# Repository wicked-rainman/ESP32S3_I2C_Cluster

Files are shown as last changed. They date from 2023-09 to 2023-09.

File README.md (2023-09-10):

## ESP32-S3 I2C Cluster

An ESP32S3 I2C cluster that captures WiFi beacon packets and outputs records that allow for a network map to be drawn (I've been using the .dot processor and Gephi for the followon processing).

### Background

Outside of my office window, I tend to see around 60 WiFi networks (Some hidden, some not). It's not much of a performance guide, but tests show that this cluster and the I2C bus easily keeps up with the beacon generation rate. 

Any drawn network diagrams tend to get bogged down with probes from rolling macs generated by mobile phones. I tend to just filter these out with post processing (often by Vendor OUI), but even after doing that, the inter-relationship between various WiFi networks was surprising to me.

Many of the domestic APs observed seem to offer multiple WiFi networks for roving users. These devices tend to use a rolling Mac address that is similar to the advertised network's Mac (For example, "Bt-WiFi" seems to offer a home network, a public network and one that is hidden). Where this is the case, the SSID for the roving network is associated with the fixed Mac that relates to the visible home user SSID (This is a function of the Network scanning node).

As I'm only really interested in trying to draw network maps, the Master node performs a dedupe based on the concatenation of the first three Mac addresses in any beacon packets. The dedupe "buffer" is in fact two fifo buffers. One for real macs and the other for rollers. The rolling mac buffer is roughly four times bigger, because that seems to suit the local traffic I see.

I've had a go at doing this because people tend to pour scorn on folk making mini clusters, often saying it's a waste of time. I think it's all about the use case. Using M5StampS3 modules, this cluster cost about half the price of a Raspberry Pi and it seems quite effective. Logic flow for this cluster is as follows:

### I2C Startup
Master I2C node makes connection attempts to the three other nodes. If an Ack is not received processing stops and the Master node LED flashes red. If there is a USB Serial connection made, diagnostic messages indicate which node cannot be contacted.

```mermaid
sequenceDiagram
    autonumber
    Master->>Oui node: I2C Poll 0x57
    activate Master
    Oui node-->>Master: Poll Ack
    Master->>WiFi node: I2C Poll 0x56
    WiFi node-->>Master: Poll Ack
    Master->>Beacon node: I2C Poll 0x55
    Beacon node-->>Master: Poll Ack
    deactivate Master

```

If all nodes appear to be live, the master node processing then waits for a button press before activation. During this "dormant" period, two of the nodes start processing:
* <b>WiFi node</b>: 
Starts to scan for WiFi networks. The details of each new network are stored in a structure, indexed by BSSID, with a string value for the SSID. The structures are held in an array that holds up to 200 records. If this count is exceeded no further records are added. An I2C ISR access this buffer to answer SSID lookups requested by the master, so there isn't the processing time available to make the array a link list.

* <b>Beacon node</b>:
Starts to cycle through WiFi channels, storing any management beacon packets it can see. An I2C ISR sits waiting for the master to request the next beacon. Up to 255 beacons are stored in a FIFO buffer and the last but one beacon packet is returned. 

* <b>Oui node</b>
The Oui node has a pre-loaded array of Vendor strings indexed by the four byte OUI value extracted from a Mac. This array can be updated with fresh values by using Netcat on port 180. The node always listens to this port for a connection and updates can take place at any stage. 

### Running

```mermaid
sequenceDiagram
    autonumber
    Master->>Beacon node: Request next beacon
    Beacon node-->>Master: Beacon header
    Master->>Oui node: Request Mac Addr vendor
    Oui node-->> Master: Vendor or Unk
    Master->>WiFi node: Request SSID
    WiFi node-->>Master: SSID or Unk
```
1.  The master requests the next beacon packet.
2.  The beacon node returns the last available packet
3. If the ADDR1 field in the packet is not a broadcast MAC, the master extracts the four most significant bytes of the Mac address and sends it to the Oui node.
4.  The Oui node looks these four bytes up in it's OUI table and if found, returns the Vendor details or the string OUI_Unk.
5. The Master then sends the ADDR1 mac address to the WiFi node.
6. The WiFi node looks the Mac address up to see if it's seen an association with an SSID. If found, an SSID string is returned or the value NET_Unk. Macs can be short (Middle four bytes) or long (All 6 bytes). This helps with the resolution of public access points where a rolling mac address is associated with a publically available SSID (Such as Virgin_Media, BT-WiFi Etc). In this instance, the real home SSID is returned.

This process is repeated for ADDR2 and (if it's different from ADDR2) ADDR3.

### Data output format

The master node generates a single CSV type record for each unique beacon packet it sees (In this instance, unique means the concatenation of the first three Mac addresses extracted from the beacon packet have not been seen before). The output format is as follows:
+ <b>Addr</b>1 (Six 2-digit hex numbers)

+ <b>Addr2</b> (Six 2-digit hex numbers)

+ <b>Addr3</b> (Six 2-digit hex numbers) 

+ <b>Addr1 vendor</b> (Vendor string or "Roll" for rolling mac, "Bcast" for a broadcast)

+ <b>Addr1 SSID</b> (SSID string or "NET_Unk")

+ <b>Addr1 OUI</b> (Vendor string or "OUI_Unk")

+ <b>Addr2 vendor</b> (Vendor string or "Roll" for rolling mac, "Bcast" for a broadcast)

+ <b>Addr2 SSID</b> (SSID string or "NET_Unk")

+ <b>Addr2 OUI</b> (Vendor string or "OUI_Unk")

+ <b>Addr3 vendor</b> (Empty if ADDR2=ADDR3, else Vendor string or "Roll" for rolling mac, "Bcast" for a broadcast)

+ <b>Addr3 SSID</b> (Empty if ADDR2=ADDR3, else SSID string or "NET_Unk")

+ <b>Addr3 OUI</b> (Empty if ADDR2=ADDR3 else endor string or "OUI_Unk")

* <b>ADDR2 Channel number</b> (Integer)

+ <b>Beacon seq #</b> (Integer. Rolling buffer position)

<table>
  <tr>
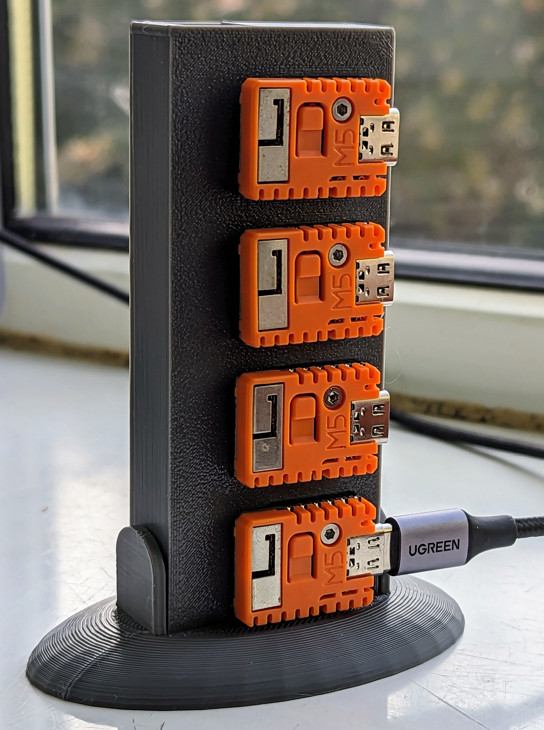
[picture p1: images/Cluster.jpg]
    <td></td>
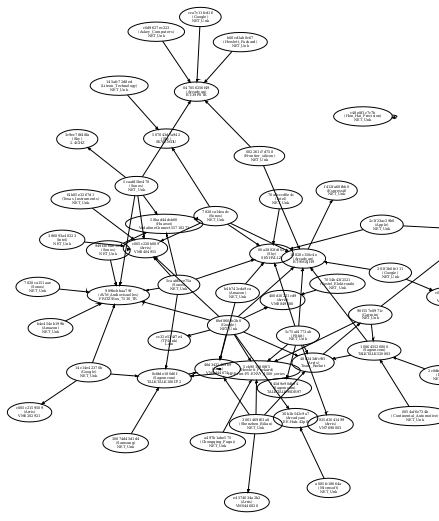
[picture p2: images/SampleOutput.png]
    <td></td>
   </tr> 
</table>

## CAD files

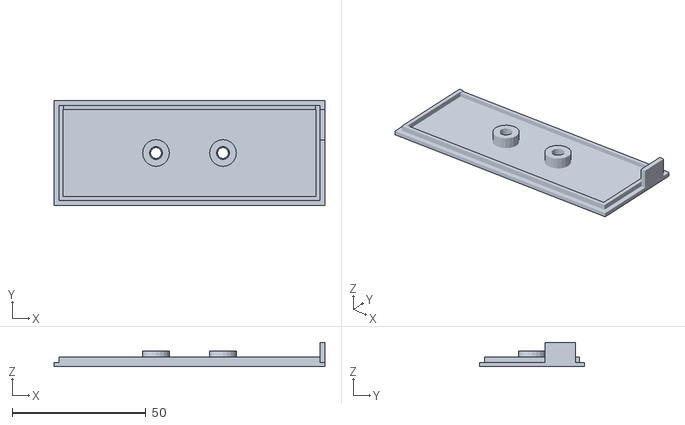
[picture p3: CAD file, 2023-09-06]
STL/Back.stl
101.2 x 39.3 x 9.00

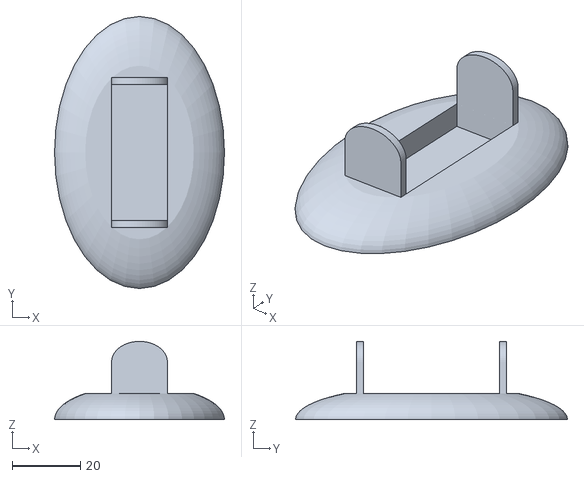
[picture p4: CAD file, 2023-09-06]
STL/Stand.stl
50.0 x 80.0 x 23.0

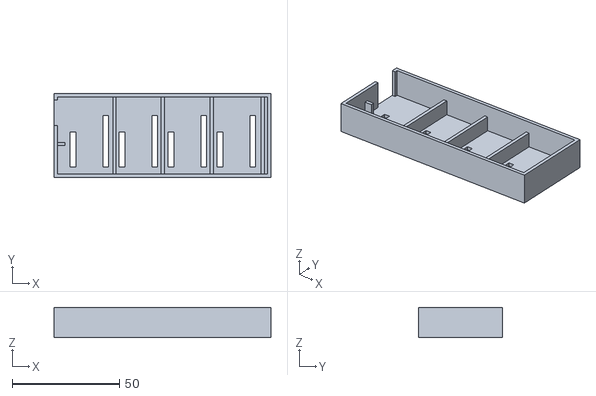
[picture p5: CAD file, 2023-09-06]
STL/Case.stl
101.2 x 39.3 x 14.0

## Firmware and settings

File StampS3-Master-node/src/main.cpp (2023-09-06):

#include "main.h"

void setup() {
  bool error=false;
  bool toggle=true;
  pinMode(PIN_BUTTON, INPUT);
  FastLED.addLeds<WS2812,LED, GRB>(leds, NUM_LEDS);
  USBSerial.begin(115200);
  vTaskDelay(1200); //This is how long Espressif seem to think the USB serial port takes to init.

  //
  // This is the I2C Master.                                                      
  // ------------------------                                                     
  // It's function is as follows:                                                 
  //                                                                              
  // 1. Make sure that the three cluster node slaves can be found                 
  //    on the I2C bus.                                                           
  //                                                                              
  // 2.Request the latest beacon packet via I2c from the Beacon node.             
  //  There is no guarantee that every beacon packet will be processed, but
  //  they are extracted from a circular buffer on the beacon node end and in 
  //  practice, very little(if any) seem to get lost.
  //
  // 3.Extract the three Mac addresses from the beacon packet
  //  and see if all three combined (18 bytes) have been seen before.
  //  We are only intrested in TA, so if it's a duplicate just ignore it.
  //
  // 4.For each of the first three Mac addresses in the beacon, check to
  // see if the address is rolling. If it is, mark it as such.
  // If it's not a rolling mac, ask the OUI node to look up the vendor,
  // then ask the network scanning node if there is an associated SSID.
  //
  // 5. Output all that gleamed information via the serial port and
  // as a broadcast on UDP port 5128.
  //
  USBSerial.printf("This is the master node\n");
  Wire.setPins(13,15);
  Wire.begin();
  vTaskDelay(5000);
  Wire.beginTransmission(0x55);
  if(!Wire.endTransmission()) USBSerial.printf("Found I2c device: 0x55\n");
  else error=true;
  Wire.beginTransmission(0x56);
  if(!Wire.endTransmission()) USBSerial.printf("Found I2c device: 0x56\n");
  else error=true;
  Wire.beginTransmission(0x57);
  if(!Wire.endTransmission()) USBSerial.printf("Found I2c device: 0x57\n");
  else error=true;
  if(error) {
    //----------------------------------------------------------------------//
    // Could not contact the three nodes, so loop forever flashing the led  //
    //----------------------------------------------------------------------//
    while(true) {
      toggle = !toggle;
      if(toggle) leds[0] = 0xff0000;
      else leds[0] = 0x000000;   
      FastLED.show();
      vTaskDelay(200);
    }
  }
  //
  // Required nodes were found.   
  // Start up WiFi connection, waiting forever if it's not there    
  //
  WiFi.begin(ssid,password);
  while(WiFi.status() != WL_CONNECTED) {
      leds[0] = 0x0000ff;
      FastLED.show();
      vTaskDelay(200);
      leds[0] = 0x000000;
      FastLED.show();
      vTaskDelay(200);
  }
  //
  // Open up the UDP broadcast port    
  //
  beaconPort.begin(UDPBEACON_PORT);

//
// Wait for a button press before running. This gives a chance for a new OUI table   
// to be NC'd up to the OUI node and allows for the Network scanner to learn for      
// a while. The longer the time delay before pressing the button the better. This    
// is because the scanner performs on-the-fly editing of SSIDs to resolve            
// rolling AP mac addresses. In practice, one or two mins before activation          
// seems a good time to chill.                                                       
//
  leds[0] = 0x0f0000;
  FastLED.show();
  while(1) {
    if(!digitalRead(PIN_BUTTON)) {
      vTaskDelay(20);
      if(!digitalRead(PIN_BUTTON)) {
        leds[0] = 0x000000;
        FastLED.show();
        vTaskDelay(2000);
        break;
      }
    }
  }
  //
  // Initialise the two ring buffers used by the concentrator function (Dedupes records based   
  // on full or rolling mac addresses). For rolling macs, only the central 4 bytes are stored   
  // (They get put in the short buffer). Full macs get stuffed into the long buffer.            
  // If either get's found, then the beacon records are dropped as "seen before"                
  //
  memset(DedupeBufLong,0,DEDUPE_LONG_BUF_SIZE);
  memset(DedupeBufShort,0,DEDUPE_SHORT_BUF_SIZE);
}
//-----------------------------------------------------------------------------

void loop() {
  static uint8_t Addr1[6];
  static uint8_t Addr2[6];
  static uint8_t Addr3[6];
  static char Addr1Oui[40];
  static char Addr2Oui[40];
  static char Addr3Oui[40];
  static char SsidStr1[200];
  static char SsidStr2[200];
  static char SsidStr3[200];
  static uint8_t ChannelNo;
  static uint8_t SequenceNo;
  static uint8_t BroadcastOui[3]={255,255,255};
  char beaconStr[BEACON_RECORD_SIZE];


  //If a new beacon packet is available
  if(FetchNextBeacon()) {
    // If we've not seen the three combined Mac addresses before
    if(Concentrate(buf)) {
      leds[0] = 0x000f00;
      FastLED.show();
      memcpy(Addr1,buf,6);
      memcpy(Addr2,buf+6,6);
      memcpy(Addr3,buf+12,6);
      ChannelNo=buf[18];
      SequenceNo=buf[19];

      //
      //  Deal with Addr1 (Often broadcast)                               
      //
      
      if (!memcmp(Addr1,BroadcastOui,3)) {  //If it's a broadcast mac
        strcpy(Addr1Oui,"Bcast");           //Don't look up the OUI
        strcpy(SsidStr1,"NET_Unk");         //Don't look up the SSID
      }
      else if(RollingMac(Addr1[0])) {       //If it's a rolling mac  
        strcpy(Addr1Oui,"Roll");            //Don't look up the OUI, set it to Roll
        ResolveSSID(Addr1,SsidStr1);      //Look for previous assoc with an SSID
      }
      else {                                //It's a normal mac
        ResolveDevice(Addr1,Addr1Oui);      //Look up the OUI
        ResolveSSID(Addr1,SsidStr1);      //Look up the SSID
      }

      //
      //  Deal with Addr2                                                
      //

      if(RollingMac(Addr2[0])) {            //If it's a rolling mac (no broadcasts in Addr2)
        strcpy(Addr2Oui,"Roll");            //Set OUI to Roll
        ResolveSSID(Addr2,SsidStr2);      //Look for an SSID match
      }
      else {                                // It's a normal mac.
        ResolveDevice(Addr2,Addr2Oui);      //Look up the OUI
        ResolveSSID(Addr2,SsidStr2);      //Look up the SSID
      }

      //
      //  Deal with Addr3 if it's not the same as Addr2                   
      //

      if(memcmp(Addr2,Addr3,6)) {             //If Addr2 is different from Addr3
        if (!memcmp(Addr3,BroadcastOui,3)) {  //If it's a broadcast mac
          strcpy(Addr3Oui,"Bcast");           //Set OUI to roll
          strcpy(SsidStr3,"NET_Unk");         //Set SSID to Unknown
        }
        else if(RollingMac(Addr1[0])) {       //If it's a rolling mac  
          strcpy(Addr3Oui,"Roll");            //Set OUI to roll
          ResolveSSID(Addr3,SsidStr3);      //Look up SSID
        }
        else {                                //It's a normal mac
          ResolveDevice(Addr3,Addr3Oui);      //Look up OUI
          ResolveSSID(Addr3,SsidStr3);      //Look up SSID
        }
      }
      else {                                  //MAC addr1 and addr2 the same
        SsidStr3[0]='\0';                     //Set SSID to null
        Addr3Oui[0]='\0';                     //Set OUI to null
      }
      
      //
      // Produce the output
      //
      snprintf(beaconStr,BEACON_RECORD_SIZE,"%02x%02x%02x%02x%02x%02x,%02x%02x%02x%02x%02x%02x,%02x%02x%02x%02x%02x%02x,%s,%s,%s,%s,%s,%s,%d,%d\n",
          Addr1[0],Addr1[1],Addr1[2],Addr1[3],Addr1[4],Addr1[5],
          Addr2[0],Addr2[1],Addr2[2],Addr2[3],Addr2[4],Addr2[5],
          Addr3[0],Addr3[1],Addr3[2],Addr3[3],Addr3[4],Addr3[5],
          Addr1Oui,SsidStr1,Addr2Oui,SsidStr2,Addr3Oui,SsidStr3,
          ChannelNo,SequenceNo);
          UdpWrite(&beaconPort,SendIP,UDPBEACON_PORT,beaconStr);
          USBSerial.printf("%s",beaconStr);

    }
    leds[0] = 0x000000;
    FastLED.show();
  }
}

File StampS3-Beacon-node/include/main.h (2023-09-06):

#include <WiFi.h>
#include <FastLED.h>
#include "esp_wifi.h"
#include "esp_wifi_types.h"
#include "esp_system.h"
#include "esp_event.h"
#include "esp_event_loop.h"
#include "nvs_flash.h"
#include "driver/gpio.h"
#include "defines.h"
#include "I2CBeaconSlave.h"
#include "WiFiPacketHandler.h"
SemaphoreHandle_t xShmem;
CRGB leds[NUM_LEDS];
uint8_t led_ih = 0;
uint8_t led_status = 0;
static void wifi_sniffer_packet_handler(void *buff, wifi_promiscuous_pkt_type_t type);
uint8_t level = 0, channel = 0;
uint8_t BeaconStore[BEACON_CACHE_SIZE][BEACON_REC_SIZE];
uint8_t RingBuffPos=0;
uint8_t channelSequence[CHANNEL_COUNT]={1,6,11,3,4,1,6,11,8,9,1,6,11,2,7,1,6,11,5,10};
uint8_t channelCount=CHANNEL_COUNT;

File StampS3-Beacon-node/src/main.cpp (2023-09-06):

#include "main.h"

//-------------------------------------------------------------------------------------------
void setup() {
  USBSerial.begin(115200);
  USBSerial.flush();
  vTaskDelay(1200);
  FastLED.addLeds<WS2812,LED, GRB>(leds, NUM_LEDS);
  xShmem = xSemaphoreCreateBinary();
  xSemaphoreGive(xShmem);
  nvs_flash_init();
  tcpip_adapter_init();
  wifi_init_config_t cfg = WIFI_INIT_CONFIG_DEFAULT();
  esp_wifi_init(&cfg);
  esp_wifi_set_country(&wifi_country); 
  esp_wifi_set_storage(WIFI_STORAGE_RAM);
  esp_wifi_set_mode(WIFI_MODE_NULL);
  esp_wifi_start();
  esp_wifi_set_promiscuous(true);
  USBSerial.printf("\nThis is Beacon (%s)\n\n",WiFi.macAddress().c_str());
  WiFi.mode(WIFI_STA);
  WiFi.disconnect();
  Wire.setPins(13,15);
  Wire.begin(0x55);
  Wire.onRequest(I2CBeaconSlaveRequest);
  esp_wifi_set_promiscuous_rx_cb(&WiFiPacketHandler);
}
//-------------------------------------------------------------------------------------------
void loop() {
  vTaskDelay(WIFI_CHANNEL_SWITCH_INTERVAL);;
  esp_wifi_set_channel(channelSequence[channel++], WIFI_SECOND_CHAN_NONE);
  if(channel == CHANNEL_COUNT) channel = 0;
}

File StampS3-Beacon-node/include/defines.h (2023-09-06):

#define WIFI_CHANNEL_SWITCH_INTERVAL  (300)
#define BEACON_CACHE_SIZE 256
#define BEACON_REC_SIZE 20
#define CHANNEL_COUNT 20
#define LED 21
#define NUM_LEDS 1
